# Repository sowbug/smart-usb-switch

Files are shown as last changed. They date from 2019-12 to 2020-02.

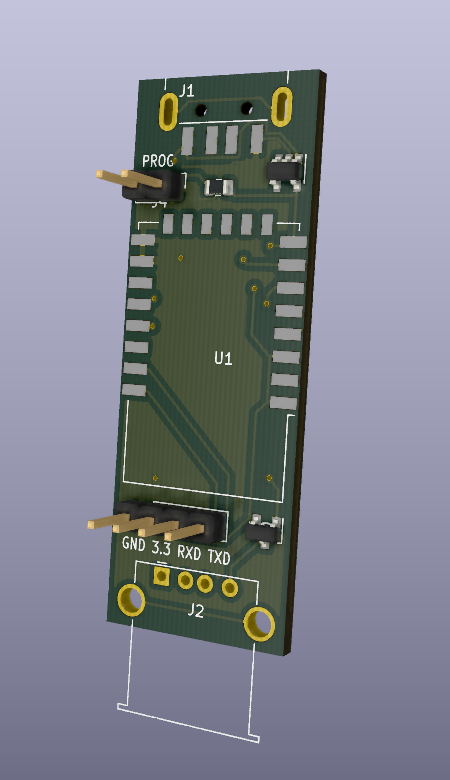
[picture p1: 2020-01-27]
3d-view.png

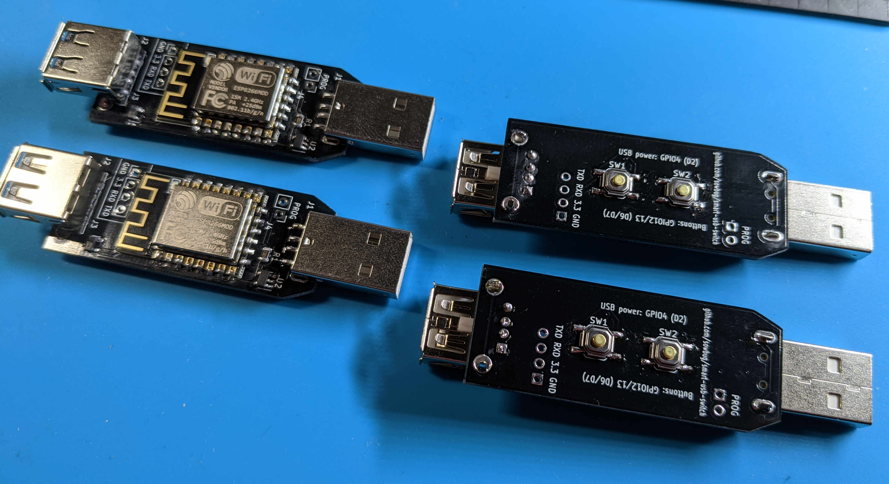
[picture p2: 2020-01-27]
completed.jpg

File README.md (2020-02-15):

# smart-usb-switch

An inline USB type-A power switch that's controlled by an ESP8266 (ESP-12F) on
GPIO4. You can load this device with any firmware you want, including for
example [ESPHome](https://esphome.io).

Version 2 has two buttons on the back. If you build this board yourself, you can
put 0, 1, or 2 of the button components in place.

The PCB could probably be a little smaller, but the ESP-12F takes up a lot of
real estate.

## How to program

These instructions are for ESPHome, but since it's just an ESP8266, you can do
anything you want instead.

Soldering jumper pins on the terminal points is optional. Get ESPHome ready with
a .yaml file like the one included in this project. Connect the PROG terminals
to each other. Using a USB-TTL adapter _that is configured to use 3.3-volt logic
levels_, connect GND, 3V3, TX, RX (in other words, match up the labels on the
USB-TTL adapter with the ones on the smart switch, but connect RX to TXD and TX
to RXD). Then build the ESPHome image and upload with
`esphome your-config.yaml run` or however else you use ESPHome.

## Bill of Materials

See `smart-usb-switch.csv`.

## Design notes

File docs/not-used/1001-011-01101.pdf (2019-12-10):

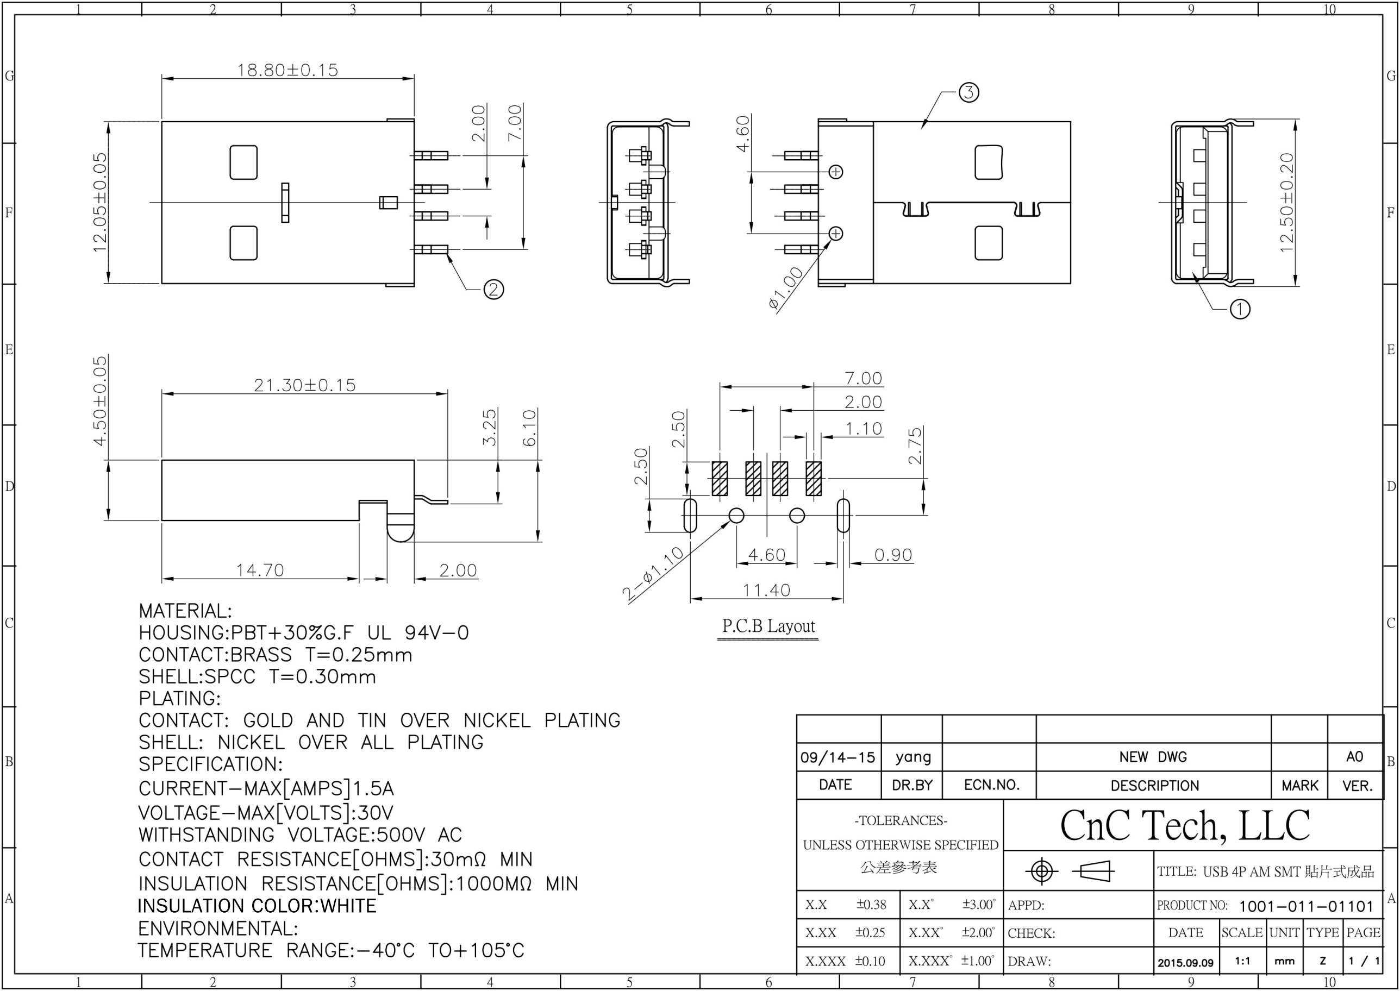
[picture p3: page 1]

INSULATIONCOLOR:WHITE

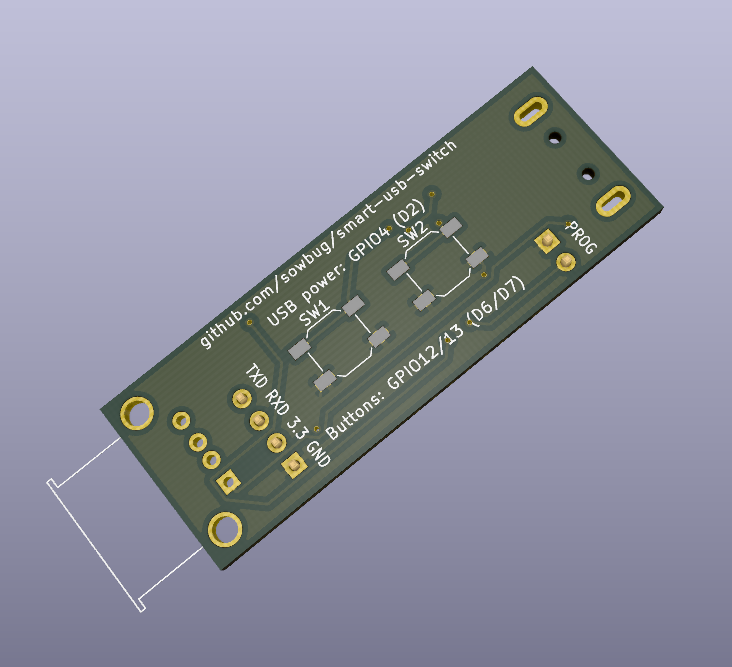
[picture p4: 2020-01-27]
3d-view-back.png

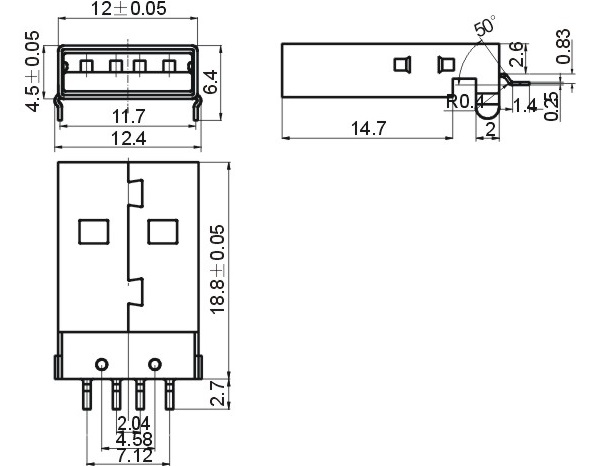
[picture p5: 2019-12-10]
docs/not-used/www.aliexpress.com-item-32900067411-html.jpg

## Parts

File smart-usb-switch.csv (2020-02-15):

Comment | Designator | Footprint | LCSC | LCSC
USB_A | J1 | Connector_USB:USB_A_CNCTech_1001-011-01101_Horizontal |  | C46394
USB_A | J2 | Connector_USB:USB_A_Stewart_SS-52100-001_Horizontal |  | C86461
Conn_01x04 | J3 | Connector_PinHeader_2.54mm:PinHeader_1x04_P2.54mm_Vertical
Conn_01x02 | J4 | Connector_PinHeader_2.54mm:PinHeader_1x02_P2.54mm_Vertical
DMN6140L-13 | Q1 | Package_TO_SOT_SMD:SOT-23 |  | C211403
R10K | R1 | Resistor_SMD:R_0805_2012Metric |  | C17414
SW_Push | SW1,SW2 | Button_Switch_SMD:SW_SPST_SKQG_WithStem |  | C318888
ESP-12F | U1 | RF_Module:ESP-12E |  | C82891
TLV75533PDBV | U2 | Package_TO_SOT_SMD:SOT-23-5 |  | C404027

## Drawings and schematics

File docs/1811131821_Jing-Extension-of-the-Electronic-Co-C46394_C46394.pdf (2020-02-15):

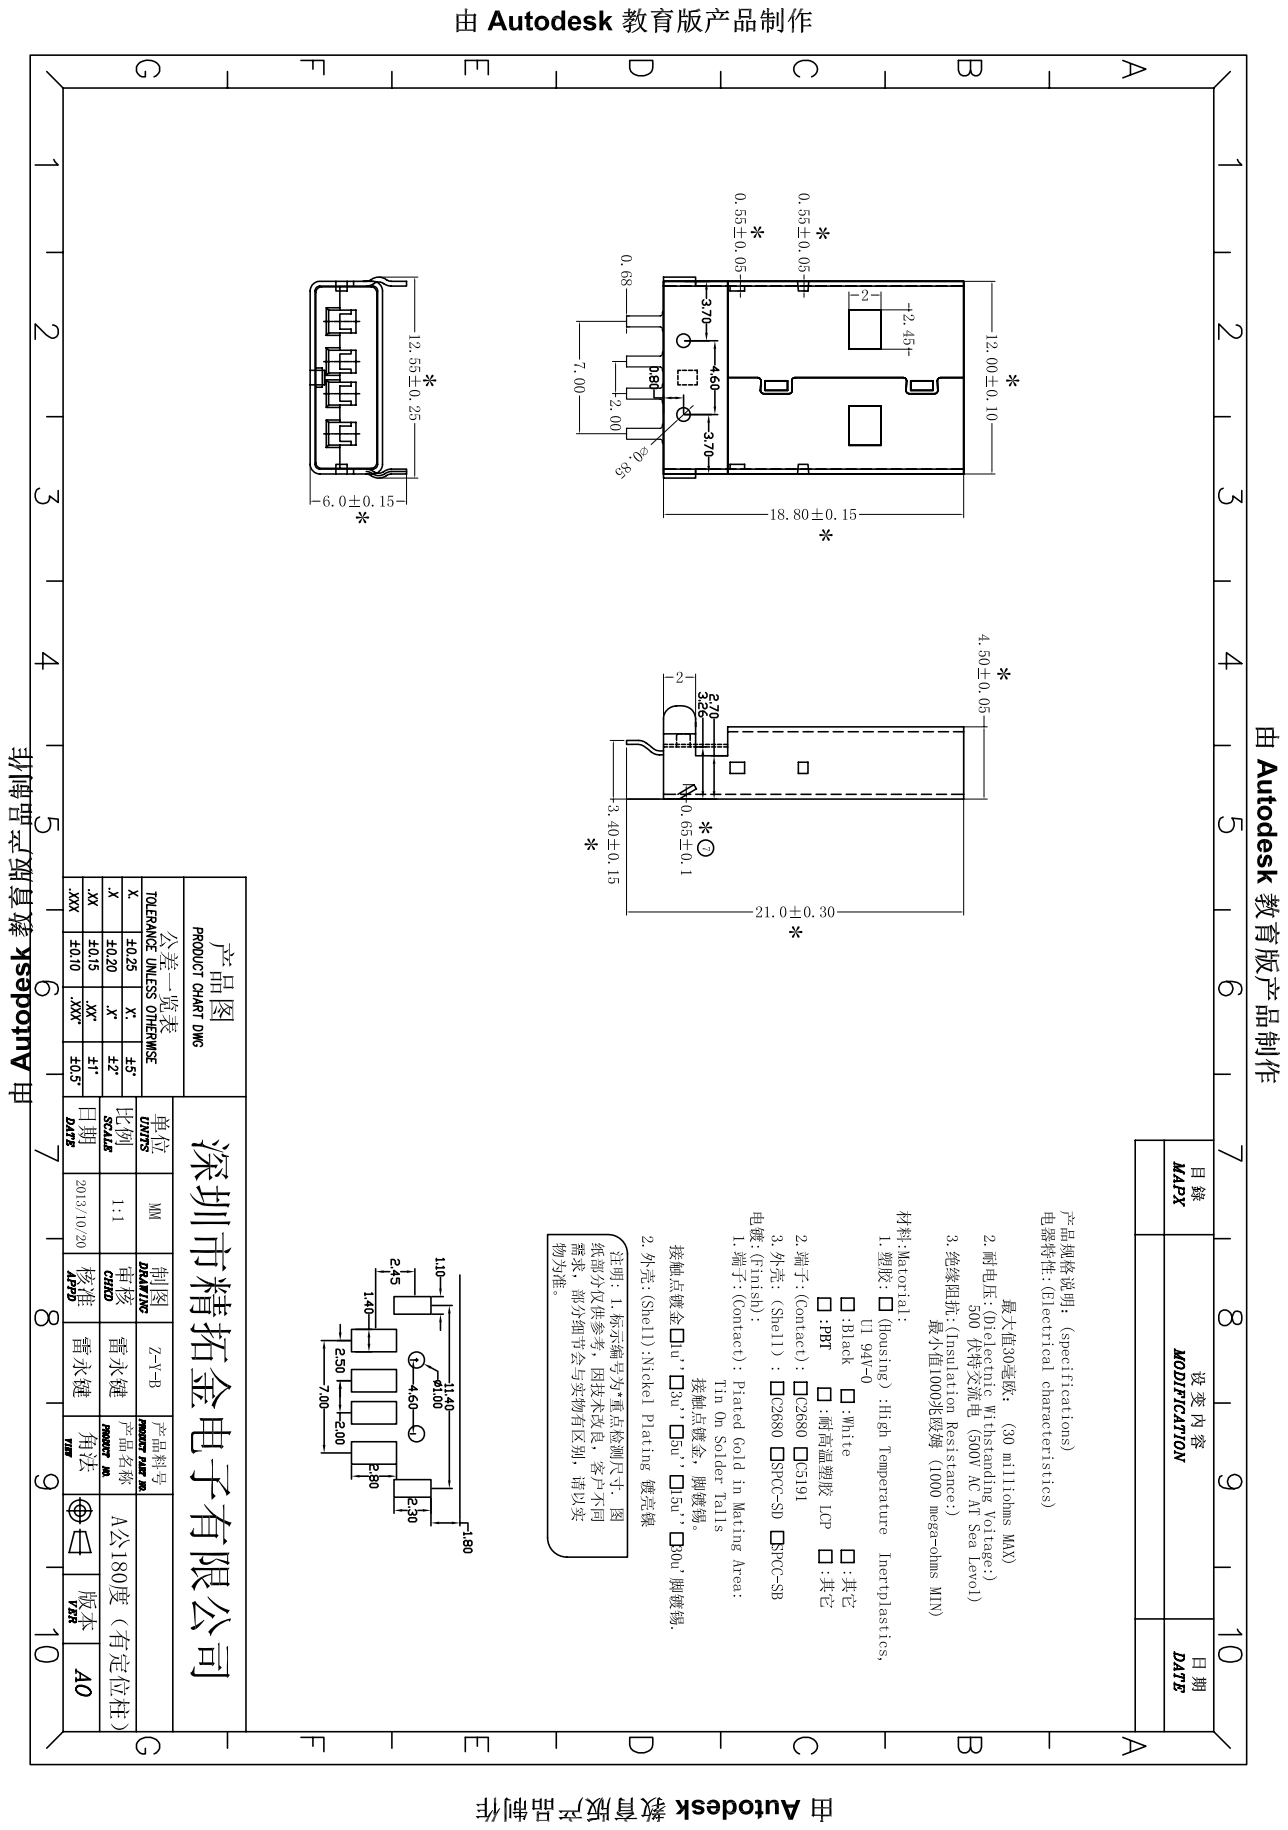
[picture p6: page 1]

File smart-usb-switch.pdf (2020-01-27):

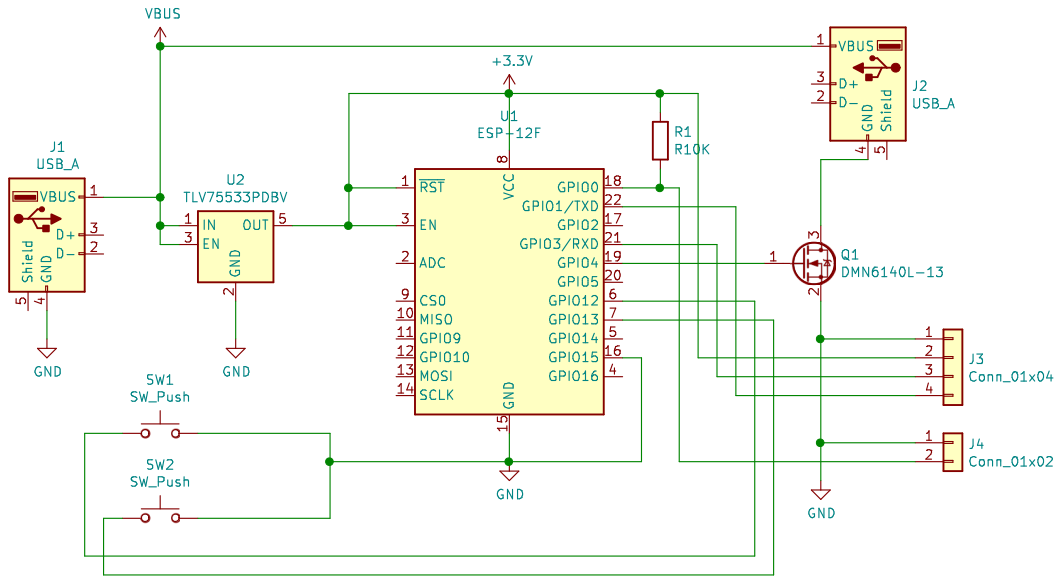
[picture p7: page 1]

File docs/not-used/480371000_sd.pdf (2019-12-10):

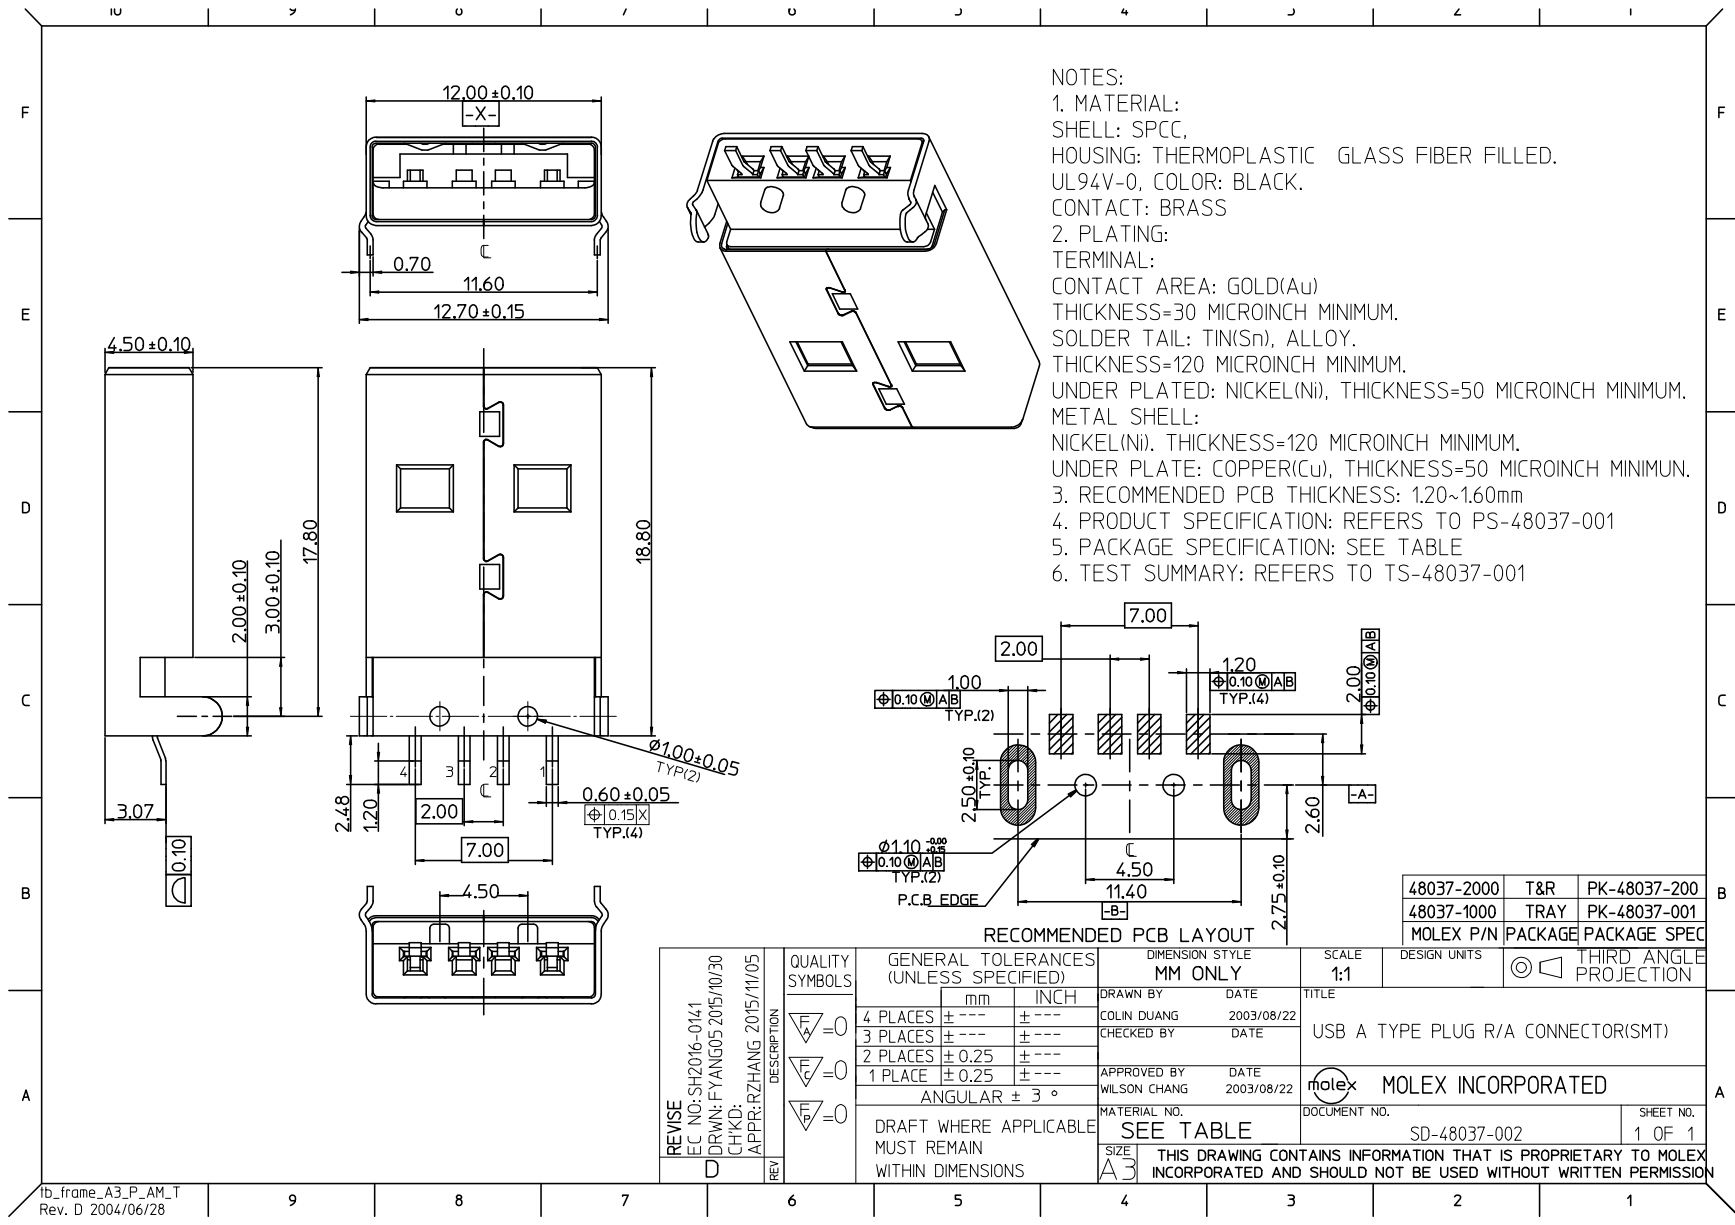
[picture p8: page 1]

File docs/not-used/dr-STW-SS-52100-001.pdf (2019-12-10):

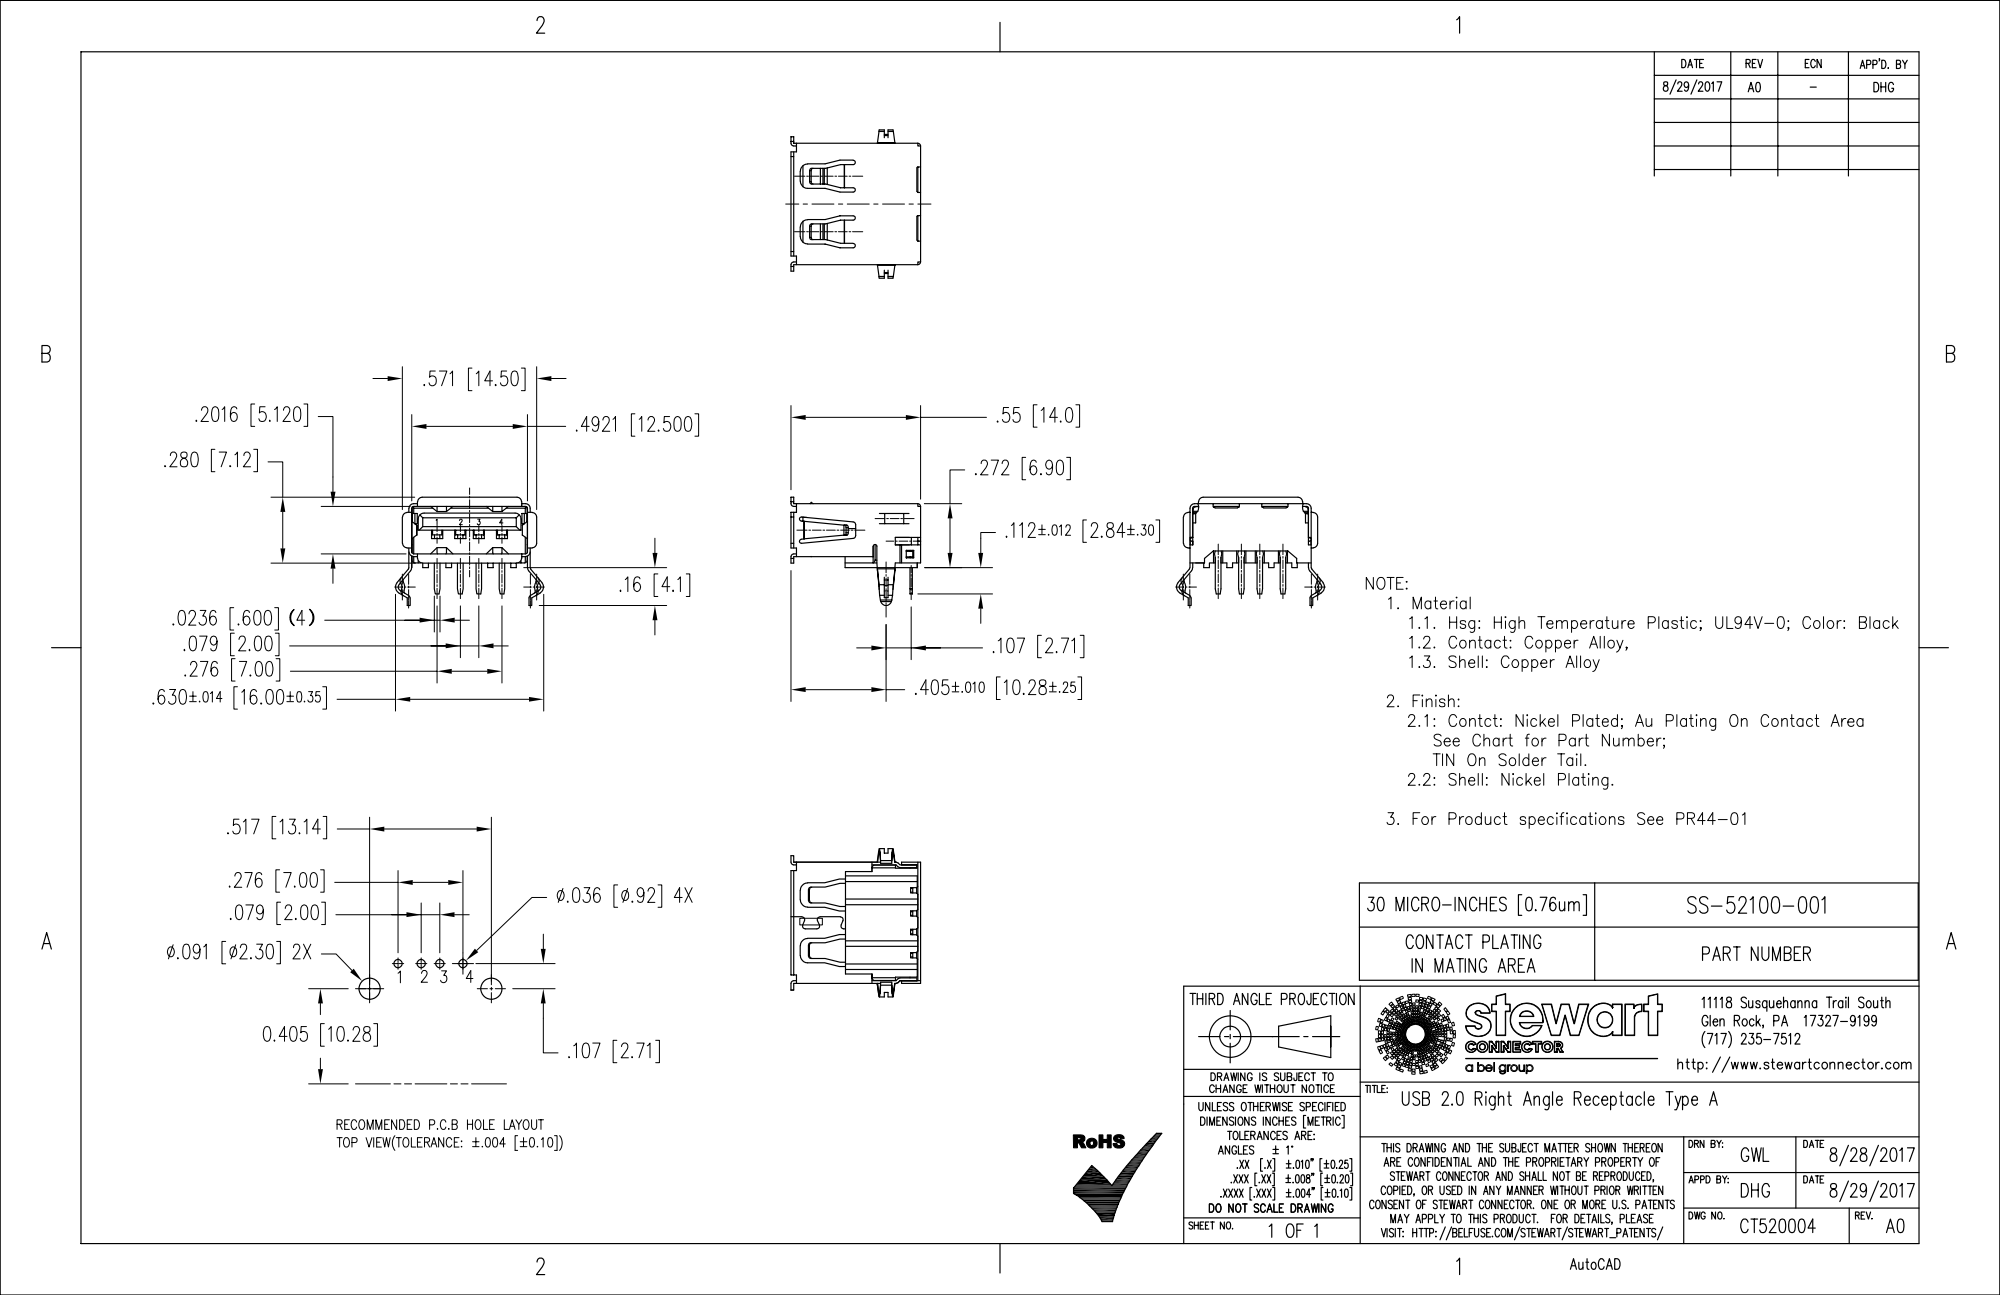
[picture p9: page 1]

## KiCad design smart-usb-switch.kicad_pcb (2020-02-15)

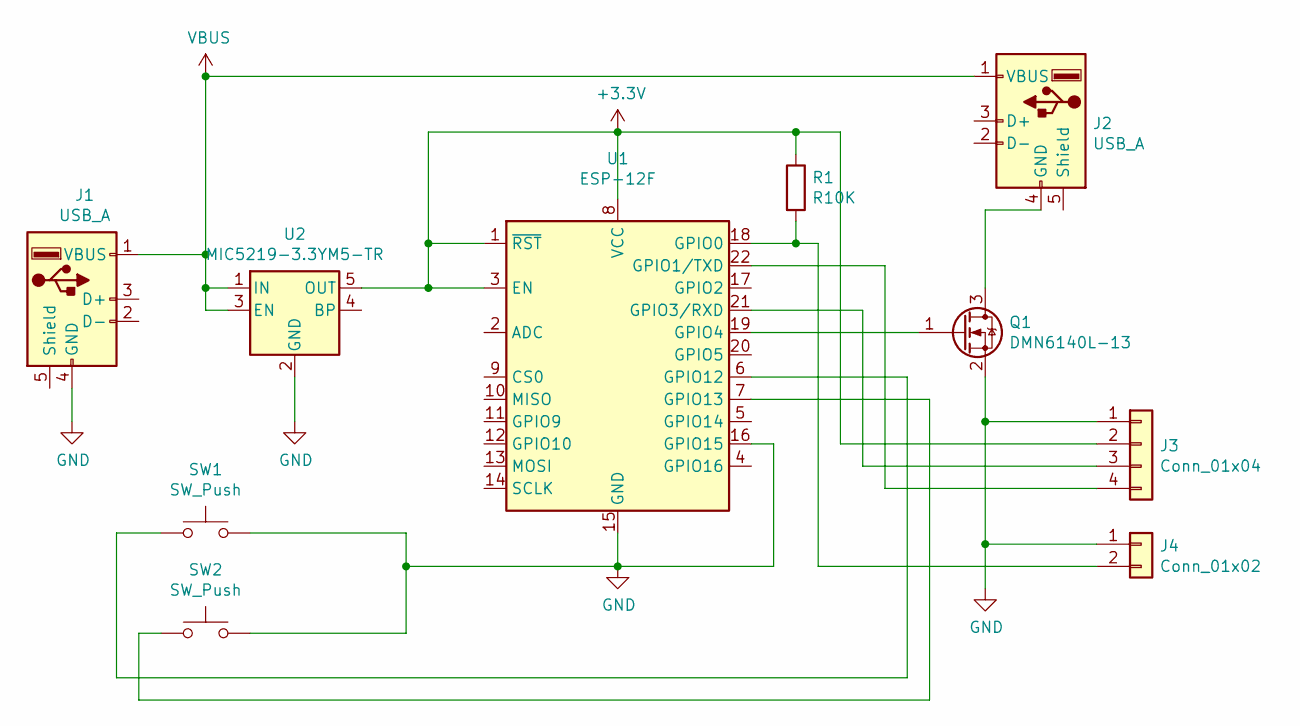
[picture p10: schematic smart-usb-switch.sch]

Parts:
J1: USB_A; USB_A_CNCTech_1001-011-01101_Horizontal; LCSC C46394
J2: USB_A; USB_A_Stewart_SS-52100-001_Horizontal; LCSC C86461
J3: Conn_01x04; PinHeader_1x04_P2.54mm_Vertical
J4: Conn_01x02; PinHeader_1x02_P2.54mm_Vertical
Q1: DMN6140L-13; SOT-23; LCSC C211403
R1: R10K; R_0805_2012Metric; LCSC C17414
SW1, SW2: SW_Push; SW_SPST_SKQG_WithStem; LCSC C318888
U1: ESP-12F; ESP-12E; LCSC C82891
U2: MIC5219-3.3YM5-TR; SOT-23-5; LCSC C29613

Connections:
+3V3: J3.2, R1.1, U1.1 (~RST), U1.3 (EN), U1.8 (VCC), U2.5 (OUT)
GND: J1.4 (GND), J3.1, J4.1, Q1.2 (S), SW1.2, SW2.2, U1.15 (GND), U1.16 (GPIO15), U2.2 (GND)
unnamed: J2.4 (GND), Q1.3 (D)
unnamed: J3.3, U1.21 (GPIO3/RXD)
unnamed: J3.4, U1.22 (GPIO1/TXD)
unnamed: J4.2, R1.2, U1.18 (GPIO0)
unnamed: Q1.1 (G), U1.19 (GPIO4)
unnamed: SW1.1, U1.6 (GPIO12)
unnamed: SW2.1, U1.7 (GPIO13)
VBUS: J1.1 (VBUS), J2.1 (VBUS), U2.1 (IN), U2.3 (EN)

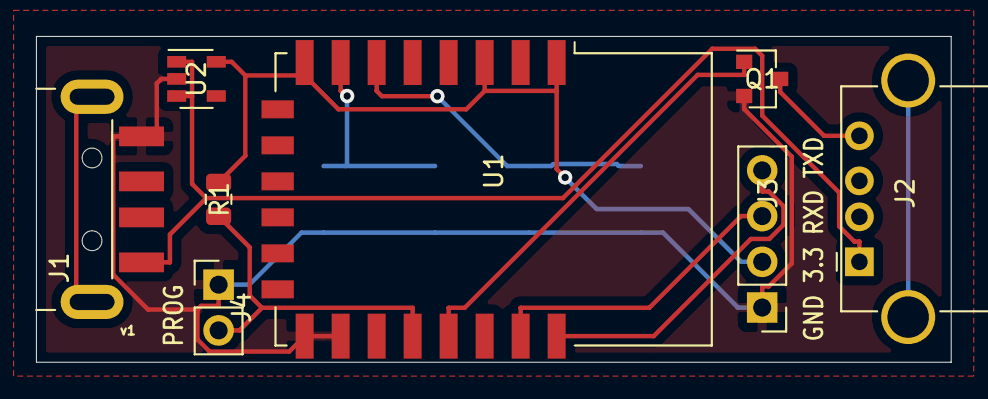
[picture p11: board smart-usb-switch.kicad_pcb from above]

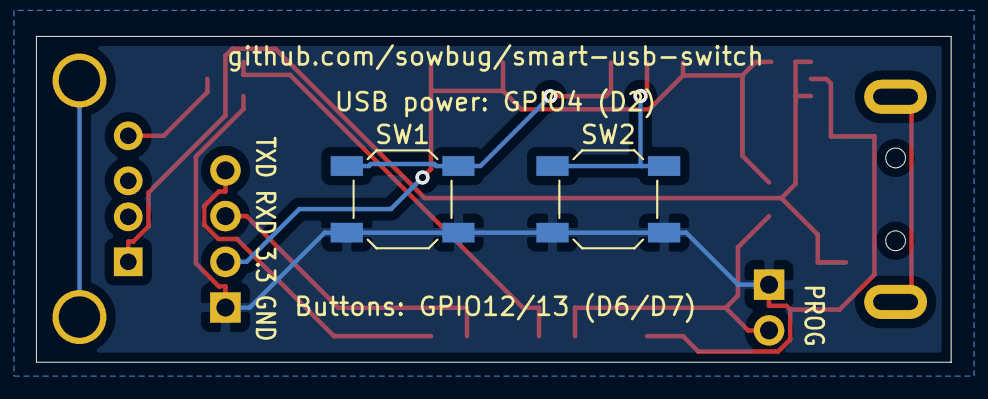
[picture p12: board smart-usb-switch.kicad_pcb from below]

Board: 2 copper layers, 50.8 x 18.1 mm, 10 parts (2 on the bottom side), 10 nets.

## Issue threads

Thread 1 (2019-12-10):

USB socket is briefly powered when first plugging in device

sowbug, 2019-12-10:

sowbug, 2019-12-10:
See http://rabbithole.wwwdotorg.org/2017/03/28/esp8266-gpio.html: behavior of GPIO14 on boot "High, then low after ~110ms."

Switch to GPIO4 or GPIO5 for low at boot.

Closed 2019-12-10.

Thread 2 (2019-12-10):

USB plug doesn't fit board

sowbug, 2019-12-10:
The two through-hole wings have protrusions that won't fit through the oval holes

The two pegs are too big for the PCB holes

The whole footprint is inset too far, so that the lip won't fit over the end of the board

Closed 2019-12-10.

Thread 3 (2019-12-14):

Add at least a footprint for a button

sowbug, 2019-12-14:
So that switches can have physical switches as well.

sowbug, 2020-01-27:
Fixed in 5e23a3f03aaa5eb8aca4fb3a57f24d685da18505

Closed 2020-01-27.

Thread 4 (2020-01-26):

Datalines

dartfrogdk, 2020-01-26:
Would be nice if the data lines where connected directly usb to usb

sowbug, 2020-01-27:
Thanks for the comments, @dartfrogdk! I'm open to the idea of passing the data lines straight through, but I wonder whether it'd be confusing to potential users of the device, because it's unusual to connect/disconnect only _some_ of the four USB lines. I'd also worry that some devices would behave incorrectly in that case.

What do you think? Are there specific devices where you think it'd be useful to have both switched power and live data lines?

dartfrogdk, 2020-01-27:
Only the powerlines should be switched, the datalines should go directly,
if you are using this device on a newer usb powerbank with higher charge
voltage, i dont think it will work unless the datalines is connected all
the time, since it have to identify, the chargevoltage.

[image: Mailtrack]
<https://mailtrack.io?utm_source=gmail&utm_medium=signature&utm_campaign=signaturevirality5&>
Sender
notified by
Mailtrack
<https://mailtrack.io?utm_source=gmail&utm_medium=signature&utm_campaign=signaturevirality5&>
27.01.20
07.17.51

Den man. 27. jan. 2020 kl. 04.35 skrev Mike Tsao <notifications@github.com>:

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

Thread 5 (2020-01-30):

PROG jumper should have a footprint for a button

sowbug, 2020-01-30:
It would be nice to have room for a real button to optionally solder it in place for development devices. The jumper works fine for devices that are wire-programmed just once or twice, but for repeated programming it can be a drag.

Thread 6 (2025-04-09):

What would it cost to create an enhanced version with current measurement?

Rudd-O, 2025-04-09:
I have a specific need for this switch, but using the INA219 to feed current measurements via ADC/I2C (not clear to me what's best) to the ESP, so as to monitor current in the +5VDC sent to the device powered by this switch.  Think Sinilink USB WF switch but with current measurement.

One use among others I have planned is to detect when old + dumb phones are in their final charging phase and stop charging them for a time.

What would it cost me to commission the design + BOM of such a thing, such that it is ready to send to JLCPCB for manufacture?  I would of course let you release the improvements under the same open source license.  I'd also contribute the design of a 3D printed case for the device.

Name your price.  Thanks in advance.

sowbug, 2025-04-09:
Hi @Rudd-O, I'm not a hardware engineer, and not much of a software engineer anymore since retiring a few years ago, so I'm hesitant to take real dollars for work of only aspirational quality. Why don't we continue this conversation over email? I'm mike@ the domain in my profile.

Rudd-O, 2025-04-09:
Thanks.  Sent you an e-mail.

Closed 2025-04-09.

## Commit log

2019-12-10 First commit after successful build.
    Built at https://oshpark.com/shared_projects/oemoKIwf
    Main bug with this version is the switch flashes briefly on
    when it's first plugged in.
    [smart-usb-switch.kicad_pcb, smart-usb-switch.sch]
2019-12-10 Fix #1: switch to GPIO4
    [smart-usb-switch.kicad_pcb, smart-usb-switch.sch]
2019-12-10 Updated current components
2019-12-10 more docs, updates
    [smart-usb-switch.kicad_pcb, smart-usb-switch.sch]
2019-12-10 Socket datasheets
2019-12-11 update schematic image
    [smart-usb-switch.kicad_pcb]
2020-01-08 update components to standard library
    [smart-usb-switch.kicad_pcb, smart-usb-switch.sch]
2020-01-09 Add buttons. Reroute, improve docs
    [smart-usb-switch.kicad_pcb, smart-usb-switch.sch]
2020-01-25 Make board narrower so it's more likely to fit in side-by-side USB ports
    [smart-usb-switch.kicad_pcb]
2020-01-27 Update artifacts and samples
2020-02-02 re-route with freerouting.org
    [smart-usb-switch.kicad_pcb]
2020-02-15 Add machine-readable BOM and LCSC part numbers
    [smart-usb-switch.csv, smart-usb-switch.sch]
2020-02-15 More LCSC and docs
    [smart-usb-switch.csv, smart-usb-switch.sch]
2020-02-15 JLCPCB mfg
    [smart-usb-switch.csv, smart-usb-switch.kicad_pcb, smart-usb-switch.sch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]
2020-02-15 Update BOM reference
